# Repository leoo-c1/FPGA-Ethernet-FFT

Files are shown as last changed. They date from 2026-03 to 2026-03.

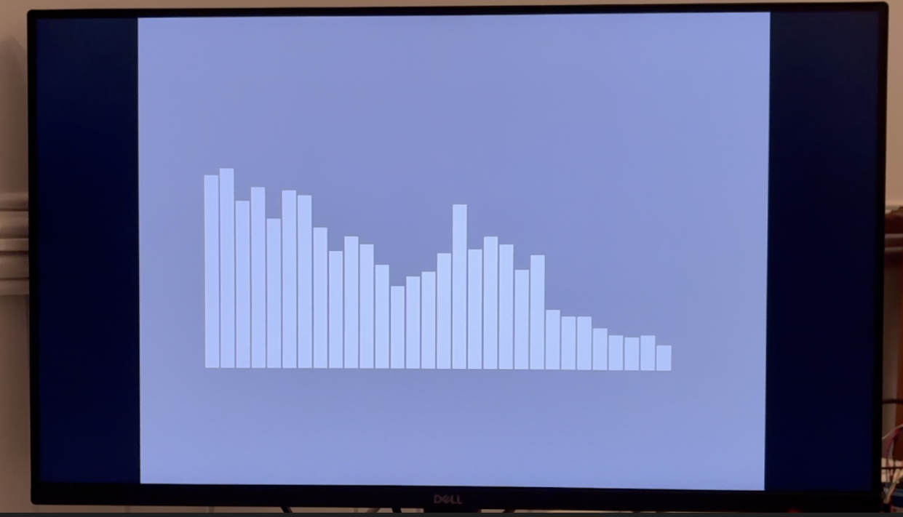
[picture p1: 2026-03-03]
media/EQ_Capture.png

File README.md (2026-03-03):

<div align="center">

# FPGA Audio Visualizer






**A 32-band audio frequency visualiser built on an FPGA. It receives audio over Ethernet, processes it using a 1024-point FFT, and logarithmically maps the frequencies to a VGA display.**

https://github.com/user-attachments/assets/8b688af6-d99d-4f4f-9ccb-69480a7465fb

</div>

## Overview

This project is a complete hardware and software pipeline for visualising audio. A custom C++ program reads WAV files and streams the raw audio data over a dedicated Ethernet link. 

The Intel Cyclone IV FPGA catches this stream using an Ethernet receiver built from scratch. It then runs the audio through a hardware Fast Fourier Transform (FFT) to break it down into frequency bins. Instead of just displaying these bins linearly, the FPGA maps them to the screen in octaves, matching human hearing, before sending the final image to a 60Hz monitor.

## System Architecture

The setup relies on the C++ program acting as a highly precise audio transmitter, while the FPGA acts as a real-time hardware receiver and audio processor.

```mermaid
graph LR
    A[C++ Program] -->|UDP Stream| B[LAN8720 PHY]
    B -->|RMII 2-bit| C(Custom Ethernet MAC)
    C -->|Audio Frames| D[Dual-Clock FIFO]
    D -->|Time-Domain| E[1024-Point FFT Core]
    E -->|Linear Bins| F[Dual-Port RAM]
    E -->|Amplitude| F[Dual-Port RAM]
    G[VGA PLL] -->|Sync & Coords| H(VGA Driver)
    F --> H
    H -->|RGB Signal| I[VGA Monitor]
```

## Features

* Custom SystemVerilog Ethernet parser that decodes physical RMII signals, extracts IPv4/UDP payloads, and drops invalid packets using real-time checksum verification.
* C++ driver that bypasses OS timing drift, maintaining perfect synchronization with the audio track.
* An exponential mathematical Look-Up Table (LUT) that maps the 512 linear FFT bins to 32 visual bands based on human octave perception: $b(x) = B_{min} \cdot (B_{max}/B_{min})^{x/(N-1)}$.
* A custom max-pooling circuit that tracks the highest peak, ensuring sharp percussion like hi-hats still make the visualiser react violently.

## Hardware Implementation

The project runs on the Intel Cyclone IV EP4CE6E22C8N FPGA using the RZ-EasyFPGA A2.2 development board. The physical layer interface is provided by a generic LAN8720 Module. A USB-C to Ethernet adapter is used to create a dedicated local network link between the host PC and the FPGA. Output is sent to a monitor via a standard VGA-to-HDMI adapter.

* FPGA: [Intel Cyclone IV EP4CE6E22C8N](https://www.intel.com/content/www/us/en/products/sku/210472/cyclone-iv-ep4ce6-fpga/specifications.html)
* FPGA Development Board: [RZ-EasyFPGA A2.2 / RZ-EP4CE6-WX board](https://web.archive.org/web/20210128152708/http://rzrd.net/product/?79_502.html)
* Ethernet PHY: [LAN8720 PHY Module](https://www.ebay.com.au/itm/233326770234)
* Ethernet Adaptor: [ALOGIC Ultra Mini USB-C to Ethernet Adapter](https://www.jbhifi.com.au/products/alogic-ultra-mini-usb-c-to-ethernet-adapter)
* VGA-to-HDMI Adapter: [eBay Listing](https://www.ebay.com.au/itm/302905294205)

### Pinout Configuration

| Signal Name | FPGA Pin | Description |
| :--- | :--- | :--- |
| `board_clk` | **PIN_23** | 50MHz Board Clock |
| `resetn` | **PIN_25** | System Reset (Active Low) |
| `phy_clk` | **PIN_88** | 50MHz PHY Reference Clock |
| `rx0` | **PIN_76** | RMII Data Bit 0 |
| `rx1` | **PIN_77** | RMII Data Bit 1 |
| `data_valid` | **PIN_83** | RMII Carrier Sense / Data Valid |
| `tx_en` | **PIN_74** | RMII Transmit Enable |
| `red` | **PIN_106** | VGA Red Channel (1-bit) |
| `green` | **PIN_105** | VGA Green Channel (1-bit) |
| `blue` | **PIN_104** | VGA Blue Channel (1-bit) |
| `h_sync` | **PIN_101** | VGA Horizontal Sync |
| `v_sync` | **PIN_103** | VGA Vertical Sync |

## Software Implementation

The audio transmitter is a C++ GUI application. Because the custom FPGA logic only listens for data and doesn't handle full two-way software handshakes (like ARP replies), you have to tell Windows exactly where to send the packets. 

This can be done by running a command in an Admin terminal to link the FPGA's IP address to its physical MAC address:

```cmd
netsh interface ip add neighbors "Ethernet Interface Name" 192.0.2.146 00-1A-2B-3C-4D-5E
```

## Project Directory
```text
├── quartus/               # Quartus Prime project files and QSF constraints
├── audio/                 # Example .wav files to use with the visualiser
├── rtl/
│   ├── core/              # Project-specific logic (Top level, memory writers, VGA driver)
│   ├── eth/               # Custom RMII Ethernet MAC and UDP Parser
│   ├── fft/               # Quartus 1024-Point Audio FFT IP
│   ├── fifo/              # Dual-Clock FIFO IP
│   ├── ram/               # Dual-Port RAM IP
│   └── vga/               # VGA sync generators and 25.175MHz PLL
├── tb/                    # Questa testbenches and Signal Tap setup files
└── software/
    └── main.cpp           # C++ Transmitter GUI
```

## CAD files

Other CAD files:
tb/stp1.stp

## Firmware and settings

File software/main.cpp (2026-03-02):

#define _USE_MATH_DEFINES
#include <cmath>
#include <iostream>
#include <vector>
#include <thread>
#include <chrono>
#include <atomic>
#include "EthSender.h"
#include <windows.h>
#include <mmsystem.h>
#include "WavParser.h"

#pragma comment(lib, "winmm.lib")       
#pragma comment(lib, "comdlg32.lib")

// GUI state variables
std::string selected_wav_path = "";
std::atomic<bool> is_playing(false);
std::atomic<bool> stop_requested(false);

// GUI element handlers
HWND hPathLabel;
HWND hBtnSelect, hBtnStart, hBtnStop;

// Background audio and network thread
void AudioStreamingTask(std::string wav_file_path, std::string fpga_ip, int fpga_port) {
    is_playing = true;
    timeBeginPeriod(1);

    std::cout << "Starting wav parser..." << std::endl;
    WavParser parser(wav_file_path);
    
    if (!parser.parse()) {
        std::cout << "Error: Unable to parse wav file" << std::endl;
        is_playing = false;
        timeEndPeriod(1);
        return;
    }

    const std::vector<int16_t>& audio_track = parser.getAudioData();
    uint32_t file_sample_rate = parser.getSampleRate();
    std::cout << "Loaded " << audio_track.size() << " total samples into memory" << std::endl;

    std::cout << "Starting ethernet sender" << std::endl;
    EthSender sender(fpga_ip, fpga_port);

    WAVEFORMATEX wfx = {0};
    wfx.wFormatTag = WAVE_FORMAT_PCM;
    wfx.nChannels = 1;
    wfx.nSamplesPerSec = file_sample_rate;
    wfx.wBitsPerSample = 16;
    wfx.nBlockAlign = (wfx.nChannels * wfx.wBitsPerSample) / 8;
    wfx.nAvgBytesPerSec = wfx.nSamplesPerSec * wfx.nBlockAlign;
    wfx.cbSize = 0;

    HWAVEOUT hWaveOut;
    if (waveOutOpen(&hWaveOut, WAVE_MAPPER, &wfx, 0, 0, CALLBACK_NULL) != MMSYSERR_NOERROR) {
        std::cout << "Error: Failed to open system audio device" << std::endl;
        is_playing = false;
        timeEndPeriod(1);
        return;
    }

    WAVEHDR waveHeader = {0};
    waveHeader.lpData = (LPSTR)audio_track.data();
    waveHeader.dwBufferLength = audio_track.size() * sizeof(int16_t);
    
    waveOutPrepareHeader(hWaveOut, &waveHeader, sizeof(WAVEHDR));
    
    std::cout << "Starting audio playback" << std::endl;
    waveOutWrite(hWaveOut, &waveHeader, sizeof(WAVEHDR));

    const size_t FRAME_SIZE = 1024;
    
    // Precompute the Hann window
    std::vector<double> hann_window(FRAME_SIZE);
    for (size_t i = 0; i < FRAME_SIZE; ++i) {
        hann_window[i] = 0.5 * (1.0 - std::cos(2.0 * M_PI * i / (FRAME_SIZE - 1)));
    }

    size_t total_samples = audio_track.size();
    auto playback_start_time = std::chrono::steady_clock::now();

    for (size_t i = 0; i + FRAME_SIZE <= total_samples; i += FRAME_SIZE) {
        if (stop_requested) break;          

        std::vector<int16_t> frame(audio_track.begin() + i, audio_track.begin() + i + FRAME_SIZE);

        // Apply the Hann window to the frame
        for (size_t j = 0; j < FRAME_SIZE; ++j) {
            frame[j] = static_cast<int16_t>(frame[j] * hann_window[j]);
        }

        auto frame_end_time = playback_start_time + std::chrono::microseconds( ((i + FRAME_SIZE) * 1000000ULL) / file_sample_rate );

        // Send the frame once
        sender.sendFrame(frame);

        if (stop_requested) break;
        
        // Wait until it is time for the next audio frame
        std::this_thread::sleep_until(frame_end_time);
    }
    
    std::cout << "Stream ended" << std::endl;

    if (stop_requested) {
        waveOutReset(hWaveOut);     // Instantly stop the audio buffer
    } else {
        std::cout << "Waiting for audio playback to finish" << std::endl;
        while (!(waveHeader.dwFlags & WHDR_DONE)) {
            if (stop_requested) { waveOutReset(hWaveOut); break; }
            std::this_thread::sleep_for(std::chrono::milliseconds(50));
        }
    }

    waveOutUnprepareHeader(hWaveOut, &waveHeader, sizeof(WAVEHDR));
    waveOutClose(hWaveOut);
    timeEndPeriod(1);

    is_playing = false;
    stop_requested = false;
    std::cout << "Ready for next file" << std::endl;
}

// GUI handler
LRESULT CALLBACK WindowProc(HWND hwnd, UINT uMsg, WPARAM wParam, LPARAM lParam) {
    switch (uMsg) {
        case WM_COMMAND:
            if (LOWORD(wParam) == 1) {      // Select File Button
                OPENFILENAMEA ofn;
                char szFile[260] = {0};
                ZeroMemory(&ofn, sizeof(ofn));
                ofn.lStructSize = sizeof(ofn);
                ofn.hwndOwner = hwnd;
                ofn.lpstrFile = szFile;
                ofn.nMaxFile = sizeof(szFile);
                ofn.lpstrFilter = "WAV Files\0*.wav\0All Files\0*.*\0";
                ofn.nFilterIndex = 1;
                ofn.Flags = OFN_PATHMUSTEXIST | OFN_FILEMUSTEXIST;

                if (GetOpenFileNameA(&ofn)) {
                    selected_wav_path = ofn.lpstrFile;
                    SetWindowTextA(hPathLabel, selected_wav_path.c_str());
                }
            }
            else if (LOWORD(wParam) == 2) {      // Start Button
                if (!is_playing && !selected_wav_path.empty()) {
                    stop_requested = false;
                    // Detach thread to run in background without blocking GUI
                    std::thread(AudioStreamingTask, selected_wav_path, "192.0.2.146", 5005).detach();
                } else if (selected_wav_path.empty()) {
                    MessageBoxA(hwnd, "Please select a WAV file first", "Error", MB_ICONWARNING);
                }
            }
            else if (LOWORD(wParam) == 3) {     // Stop Button
                if (is_playing) {
                    stop_requested = true;
                }
            }
            break;

        case WM_DESTROY:
            stop_requested = true;              // Ensure thread dies if window is closed
            PostQuitMessage(0);
            return 0;
    }
    return DefWindowProc(hwnd, uMsg, wParam, lParam);
}

int main() {
    // Register the window class
    WNDCLASSA wc = {0};
    wc.lpfnWndProc = WindowProc;
    wc.hInstance = GetModuleHandle(NULL);
    wc.lpszClassName = "FPGAVisClass";
    wc.hbrBackground = (HBRUSH)(COLOR_WINDOW+1);

    RegisterClassA(&wc);

    // Create the window
    HWND hwnd = CreateWindowExA(
        0, "FPGAVisClass", "FPGA Audio Visualiser Controller",
        WS_OVERLAPPEDWINDOW ^ WS_THICKFRAME ^ WS_MAXIMIZEBOX,   // Make window non-resizable
        CW_USEDEFAULT, CW_USEDEFAULT, 400, 200,
        NULL, NULL, wc.hInstance, NULL
    );

    // Create GUI Controls
    hBtnSelect = CreateWindowA("BUTTON", "Select WAV File", WS_TABSTOP | WS_VISIBLE | WS_CHILD | BS_DEFPUSHBUTTON,
                                20, 20, 150, 30, hwnd, (HMENU)1, wc.hInstance, NULL);

    hPathLabel = CreateWindowA("STATIC", "No file selected", WS_VISIBLE | WS_CHILD,
                                20, 60, 340, 40, hwnd, NULL, wc.hInstance, NULL);

    hBtnStart = CreateWindowA("BUTTON", "START", WS_TABSTOP | WS_VISIBLE | WS_CHILD | BS_PUSHBUTTON,
                                20, 110, 100, 30, hwnd, (HMENU)2, wc.hInstance, NULL);

    hBtnStop = CreateWindowA("BUTTON", "STOP", WS_TABSTOP | WS_VISIBLE | WS_CHILD | BS_PUSHBUTTON,
                                140, 110, 100, 30, hwnd, (HMENU)3, wc.hInstance, NULL);

    ShowWindow(hwnd, SW_SHOW);

    // Run the Windows message loop
    MSG msg = {0};
    while (GetMessage(&msg, NULL, 0, 0)) {
        TranslateMessage(&msg);
        DispatchMessage(&msg);
    }

    return 0;
}

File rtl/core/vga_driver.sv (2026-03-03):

module vga_driver #(
    parameter bottom_margin = 150,      // How many pixels to cut off from the bottom of the EQ bands
    parameter amplitude_shift = 50,     // How far down towards the margin the amplitude gets shifted
    parameter eq_scale = 80             // How much to scale the EQ bars (this gets divided by 64)
    )(
    input logic pll_clk,                // 25.175MHz PLL clock
    input logic resetn,                 // Active low reset button

    input logic [9:0] pixel_x,          // Horizontal pixel coordinate (from 0)
    input logic [9:0] pixel_y,          // Vertical pixel coordinate (from 0)
    input logic video_on,               // Whether or not we are in the active video region

    input logic [15:0] q_amplitude,     // The stored amplitude value in ram      

    output logic [9:0] rdaddress,       // The address in RAM that we want to read from

    output logic red,                   // Pixel red value (single bit, 0v or 0.7v)
    output logic green,                 // Pixel green value (single bit, 0v or 0.7v)
    output logic blue                   // Pixel blue value (single bit, 0v or 0.7v)
    );

    logic [9:0] scaled_amplitude;
    
    // If amplitude exceeds 479 (the screen height), hold it at 479
    assign scaled_amplitude = (q_amplitude > 16'd479) ? 10'd479 : q_amplitude[9:0];

    // Delay registers for pixel_x value
    logic [9:0] pixel_x_delay_1;
    logic [9:0] pixel_x_delay_2;
    logic [9:0] pixel_x_delay_3;

    // Delay registers for pixel_y value
    logic [9:0] pixel_y_delay_1;
    logic [9:0] pixel_y_delay_2;
    logic [9:0] pixel_y_delay_3;

    // Delay registers for video_on signal
    logic vid_delay_1;
    logic vid_delay_2;
    logic vid_delay_3;

    always_ff @ (posedge pll_clk or negedge resetn) begin
        if (!resetn) begin
            rdaddress <= 10'b0;
            pixel_x_delay_1 <= 10'b0;
            pixel_x_delay_2 <= 10'b0;
            pixel_x_delay_3 <= 10'b0;
            pixel_y_delay_1 <= 10'b0;
            pixel_y_delay_2 <= 10'b0;
            pixel_y_delay_3 <= 10'b0;
            vid_delay_1 <= 1'b0;
            vid_delay_2 <= 1'b0;
            vid_delay_3 <= 1'b0;
            red <= 1'b0;
            green <= 1'b0;
            blue <= 1'b0;
        end else begin
            // Shift register (3 clock cycles) for pixel_x value
            pixel_x_delay_1 <= pixel_x;
            pixel_x_delay_2 <= pixel_x_delay_1;
            pixel_x_delay_3 <= pixel_x_delay_2;

            // Shift register (3 clock cycles) for pixel_y value
            pixel_y_delay_1 <= pixel_y;
            pixel_y_delay_2 <= pixel_y_delay_1;
            pixel_y_delay_3 <= pixel_y_delay_2;

            // Shift register (3 clock cycles) for video_on signal
            vid_delay_1 <= video_on;
            vid_delay_2 <= vid_delay_1;
            vid_delay_3 <= vid_delay_2;

            if (pixel_x >= 10'd64 && pixel_x < 10'd576) begin
                // Divide by 16 to stretch each RAM address across 16 pixels
                rdaddress <= (pixel_x - 10'd64) >> 4;
            end else if (pixel_x == 10'd799) begin
                // On the very last pixel, schedule a read from the first memory address
                rdaddress <= 10'b0;
            end

            if (vid_delay_3) begin
                if (pixel_x_delay_3 >= 10'd64 && pixel_x_delay_3 < 10'd576) begin
                    if (((pixel_x_delay_3 - 10'd64) & 10'd15) < 10'd14) begin
                        // Apply eq bar transformations, first make sure transform won't create negative amplitude
                        // Measure from the bottom of the screen, use delayed pixel_y coordinate
                        if (scaled_amplitude <= amplitude_shift) begin
                            // Amplitude is supposed to be cut off, don't show it
                            red <= 1'b0;
                            green <= 1'b0;
                            blue <= 1'b0;

                        // Measure from the bottom of the screen, use delayed pixel_y coordinate
                        end else if ((10'd479 - pixel_y_delay_3 < (eq_scale * (scaled_amplitude - amplitude_shift)) >> 6)
                                    & (10'd479 - pixel_y_delay_3 > bottom_margin)) begin
                            // Colour the bar white
                            red <= 1'b1;
                            green <= 1'b1;
                            blue <= 1'b1;
                        end else begin
                            // If we're above the bar, colour it black
                            red <= 1'b0;
                            green <= 1'b0;
                            blue <= 1'b0;
                        end
                    end else begin
                        red <= 1'b0;
                        green <= 1'b0;
                        blue <= 1'b0;
                    end
                end else begin
                    red <= 1'b0;
                    green <= 1'b0;
                    blue <= 1'b0;
                end
            end else begin
                red <= 1'b0;
                green <= 1'b0;
                blue <= 1'b0;
            end

        end
    end

endmodule

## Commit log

2026-02-19 Add sample .wav file
2026-02-19 Replace stereo wav sample file with mono
2026-02-19 Store audio data in main and print first 10 samples
2026-02-19 Fix chunk size, load first 100 samples
2026-02-20 Add getter to retrieve wav file sample rate
2026-02-20 Add getter functions for sample rate
2026-02-20 Delay sending each sample chunk for the time it plays
2026-02-20 Force enum to use 3 bits in case it uses more
2026-02-20 Add fast fourier transform altera ip core files
    [audio_fft.csv]
2026-02-20 Form logic for chaining 8-bit payloads into 16-bit
2026-02-20 Replace case with if, make sure fifo isn't full
2026-02-21 Recreate fft ip to fix licensing issue
    [audio_fft.csv]
2026-02-21 Rename temporary vga driver module
2026-02-22 Draft vga driver logic
2026-02-22 Update PLL instance to take in resetn instead of rst
    [vga_sync.v]
2026-02-22 Fix multiple drivers compiler error
2026-02-23 Get rid of recursive prints to save speed
2026-02-23 Replace FFT ip core instance to include sim files
    [audio_fft.csv]
2026-02-24 Add signal tap file for hardware debugging
    [stp1.stp]
2026-02-24 Update C++ files to split frames into half the size of fifo
2026-02-24 Pass phy_clk-driven signals to board_clk
2026-02-24 Use board clock
2026-02-24 Pass in board clock to ethernet_handler
2026-02-24 Fifo writer now uses board clock
2026-02-24 Update fifo_writer's clock, use board_clk for writing to fifo
2026-02-26 Repeatedly send frames to combat packet loss
2026-02-26 Temporarily revert back to old logic
    [vga_driver.sv]
2026-02-27 Add logarithmic sweep (20Hz - 20kHz)
2026-02-27 Use absolute time measure to prevent time drift
    [main.cpp]
2026-02-28 Move streaming to background thread, use file explorer
2026-02-28 Fix bug by resetting stop flag on thread start
    [main.cpp]
2026-02-28 Add another sample wav file
2026-03-01 Add bottom margin to cut bottom of bands
2026-03-01 Pass bottom margin into vga driver
2026-03-01 Attach a sequence ID to each half of the audio samples
2026-03-01 Add 100hz sine wave sample audio
2026-03-01 Add 400hz sine wave sample audio
2026-03-01 Check sequence IDs, reject samples with inconsistent IDs
2026-03-02 Send frame only once
2026-03-02 Apply hann window to fix spectral leakage
    [main.cpp]
2026-03-03 Fix overflow bug from comparing y to negative value
    [vga_driver.sv]
2026-03-03 Track large media files
